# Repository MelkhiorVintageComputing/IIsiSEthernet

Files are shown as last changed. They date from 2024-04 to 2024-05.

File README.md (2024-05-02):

# SEthernet for the Macintosh IIsi

This is a design for a PDS Ethernet device for the Macintosh IIsi & other macintoshes with a similar PDS slot. This is not my own design, but a redesign in a different form factor of [the SEthernet/30 for the Macintosh SE/30](https://github.com/rhalkyard/SEthernet). It's meant to be gateware- (for the CPLD), firmware- (the declaration ROM) and software-compatible (the Ethernet driver) with the original.

Known issues:
* The silkscreen for the slotid is backward between '0' and '1' (the slotid are negative logic)
* The Flash ROM is wired bit-reversed. While it has no impact on data or any regular software, it does cause an issue with the 'command bytes' from the ROM programmer - the 'command bytes' need to be bit-reversed to work, so this design is not compatible with the standard programRom.

License is the same as the original:

The hardware components of this project (board designs and programmable logic) are licensed under the Strongly-Reciprocal CERN Open Hardware License, version 2.

Please see also [the comments on licensing of the original design](https://github.com/rhalkyard/SEthernet?tab=readme-ov-file#license).

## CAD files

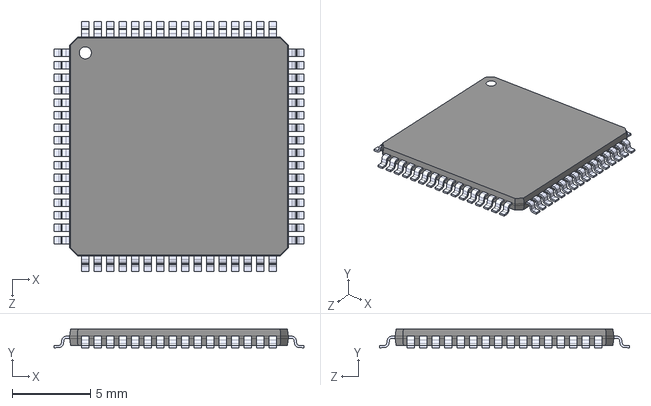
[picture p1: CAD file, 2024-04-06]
ENC624J600-I_PT.step
16.0 x 1.20 x 16.0 mm

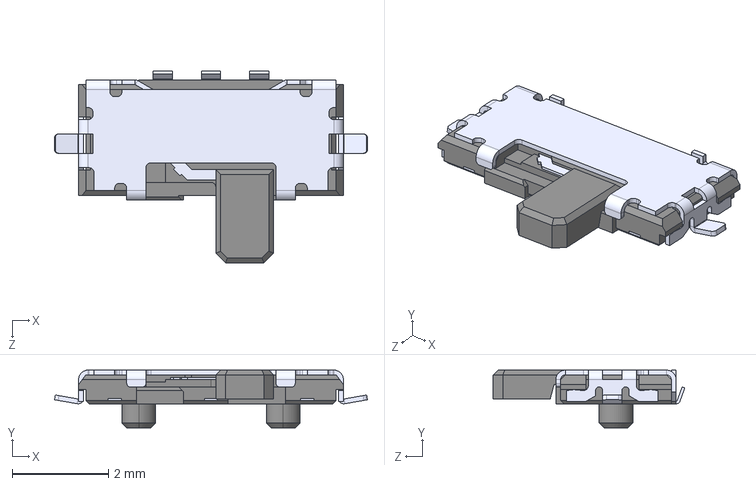
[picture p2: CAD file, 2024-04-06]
SSAJ110100.step
6.50 x 1.20 x 3.98 mm

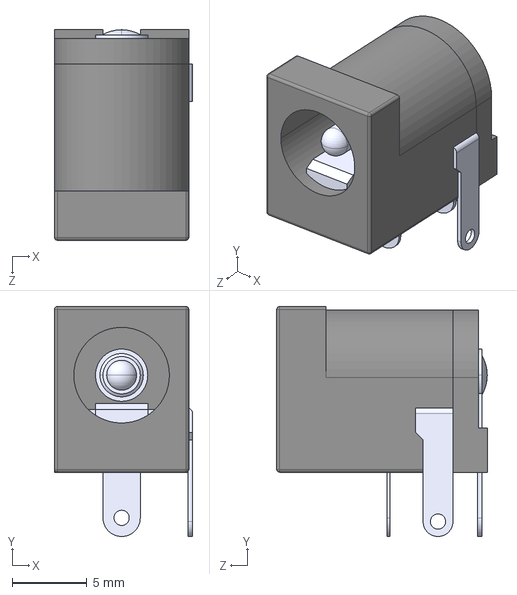
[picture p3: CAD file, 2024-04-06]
CON-SOCJ-2155--3DModel-STEP-56544.STEP
9.25 x 15.4 x 14.1 mm

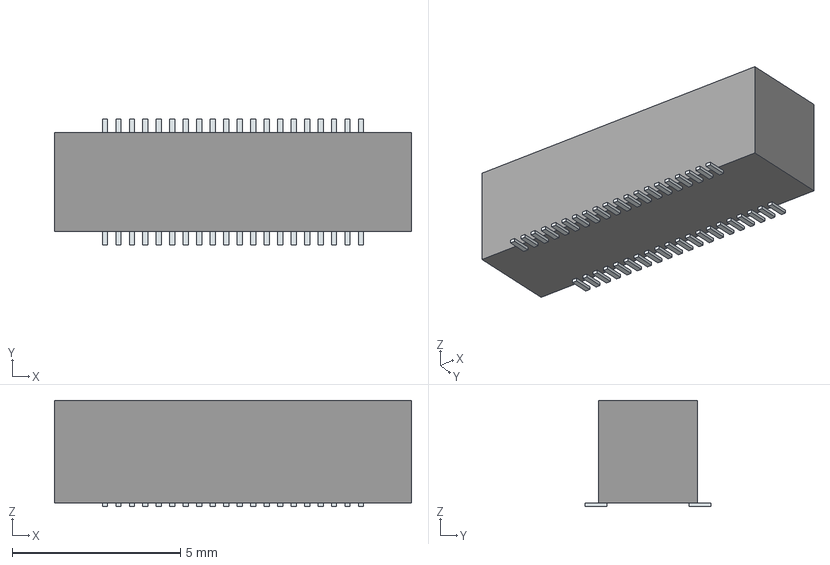
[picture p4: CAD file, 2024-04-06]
DF40HC_3.0_-40DS-0.4V_51_.stp
10.6 x 3.74 x 3.15 mm
Pins

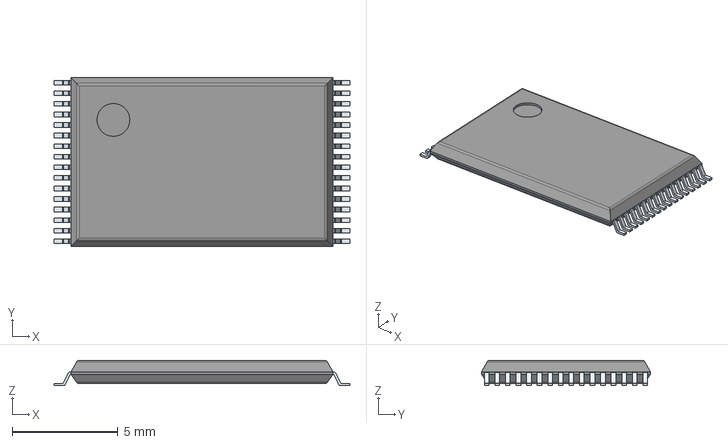
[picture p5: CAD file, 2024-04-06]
SST39SF010A-70-4C-WHE.stp
14.0 x 8.00 x 1.20 mm
PinsArrayLR

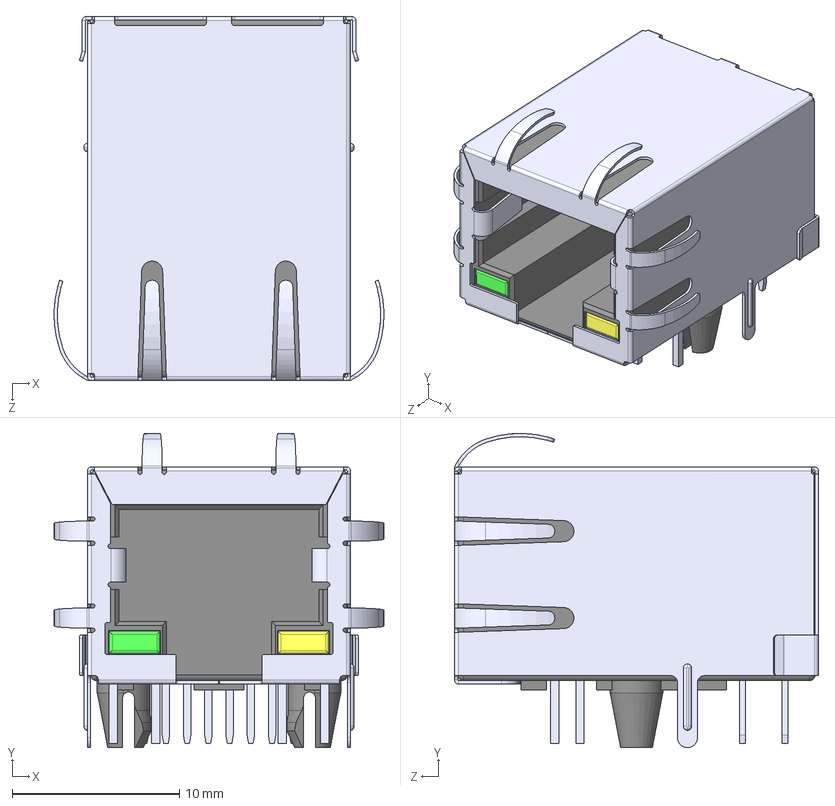
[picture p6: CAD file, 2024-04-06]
RJMG1BD3B8K1ANR--3DModel-STEP-56544.STEP
19.7 x 18.8 x 21.8 mm

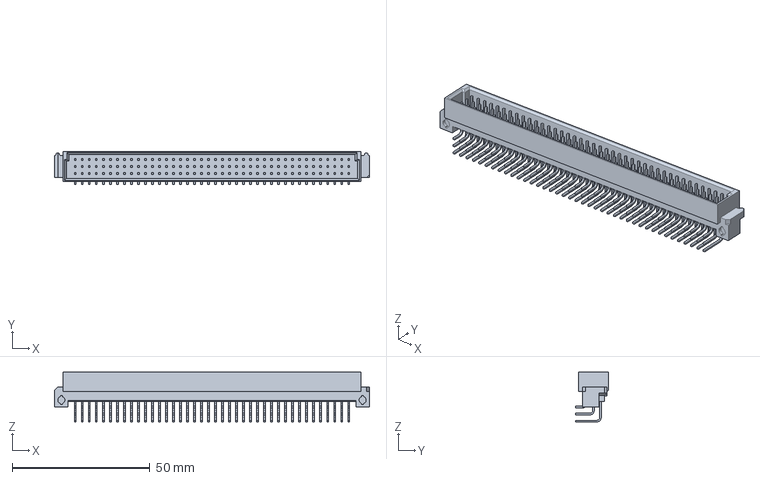
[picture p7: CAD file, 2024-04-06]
650906-5.stp
114.2 x 12.1 x 18.0 mm

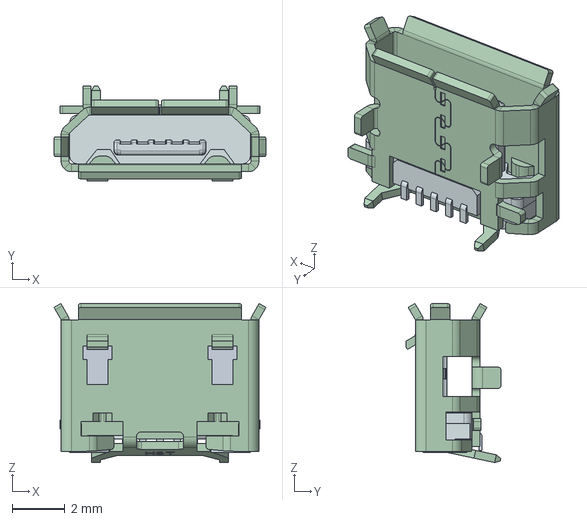
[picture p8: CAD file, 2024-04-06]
10103594-0001LF--3DModel-STEP-533217.STEP
8.04 x 3.60 x 6.03 mm

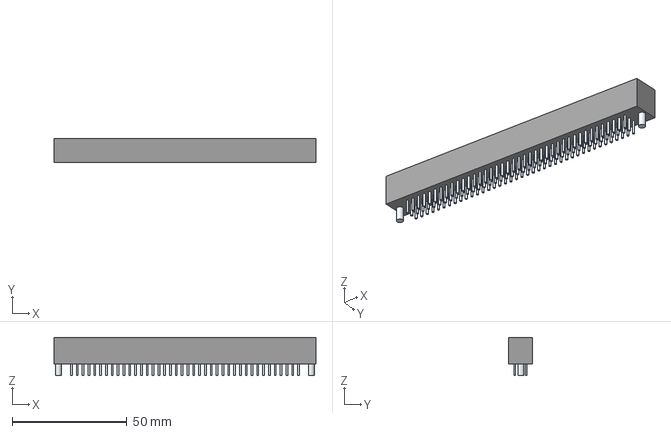
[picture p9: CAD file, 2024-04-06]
5535098-5.stp
114.3 x 10.6 x 16.6 mm
Leads

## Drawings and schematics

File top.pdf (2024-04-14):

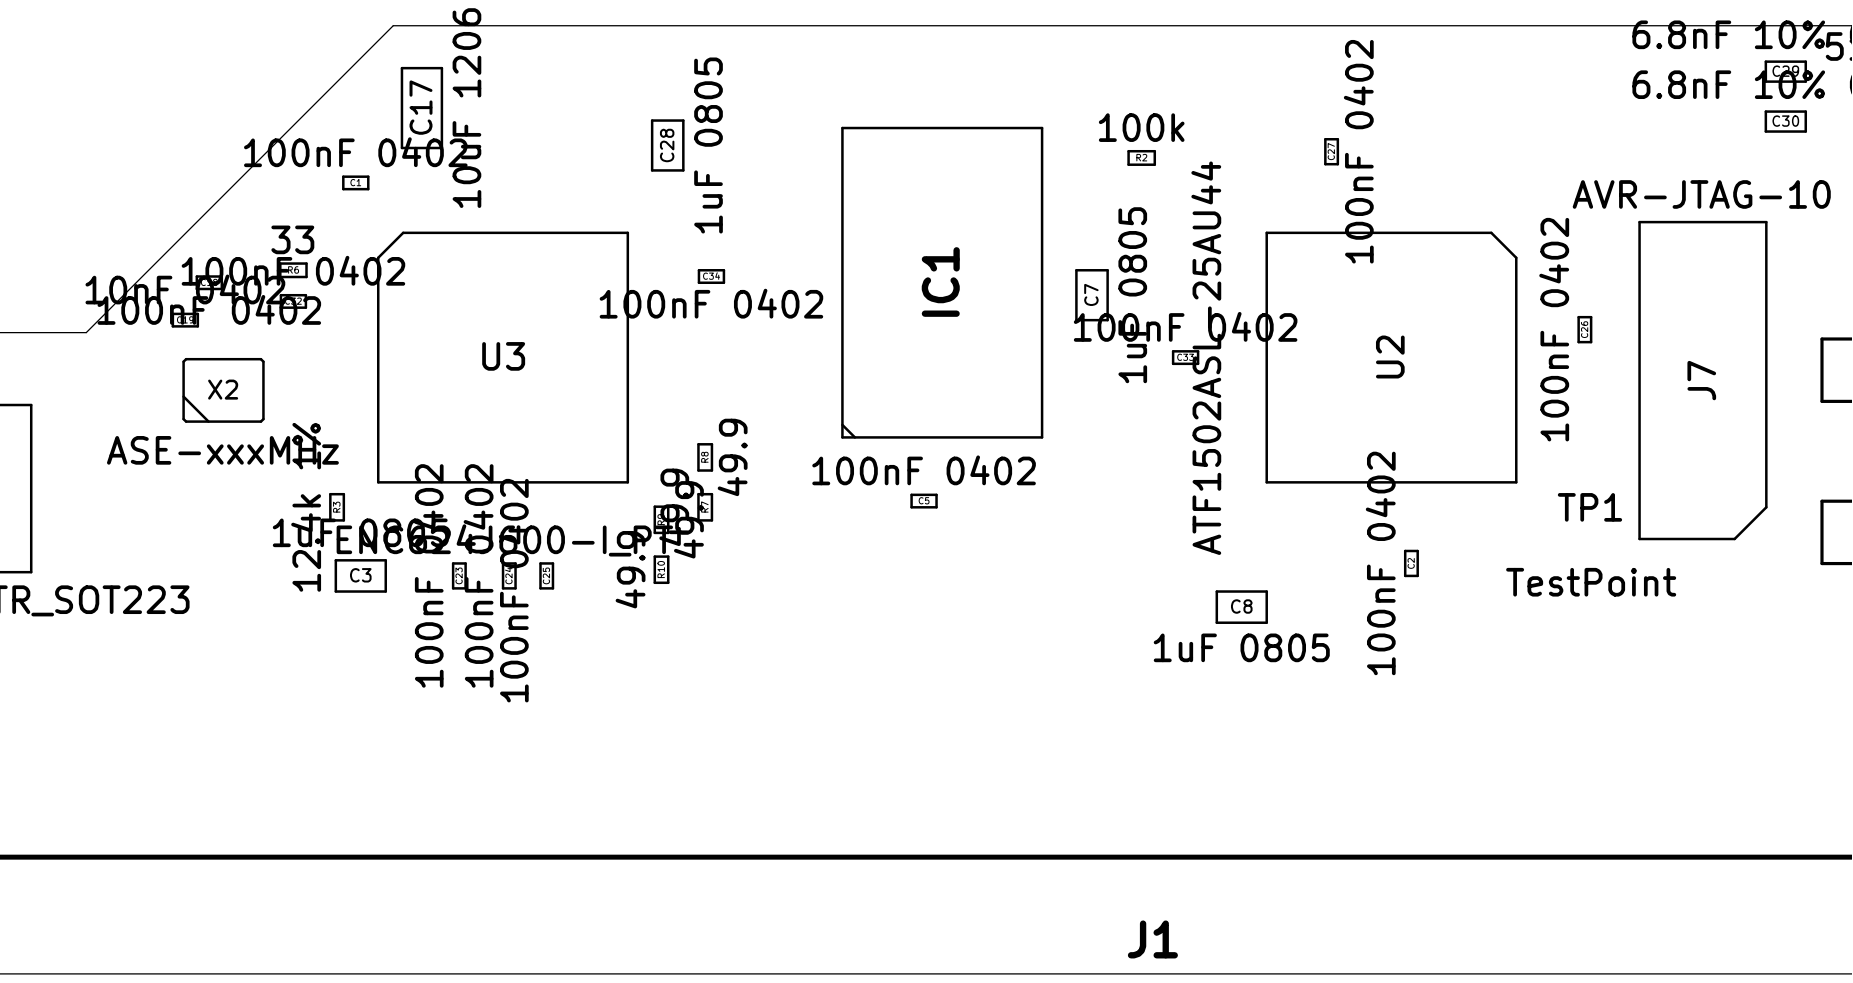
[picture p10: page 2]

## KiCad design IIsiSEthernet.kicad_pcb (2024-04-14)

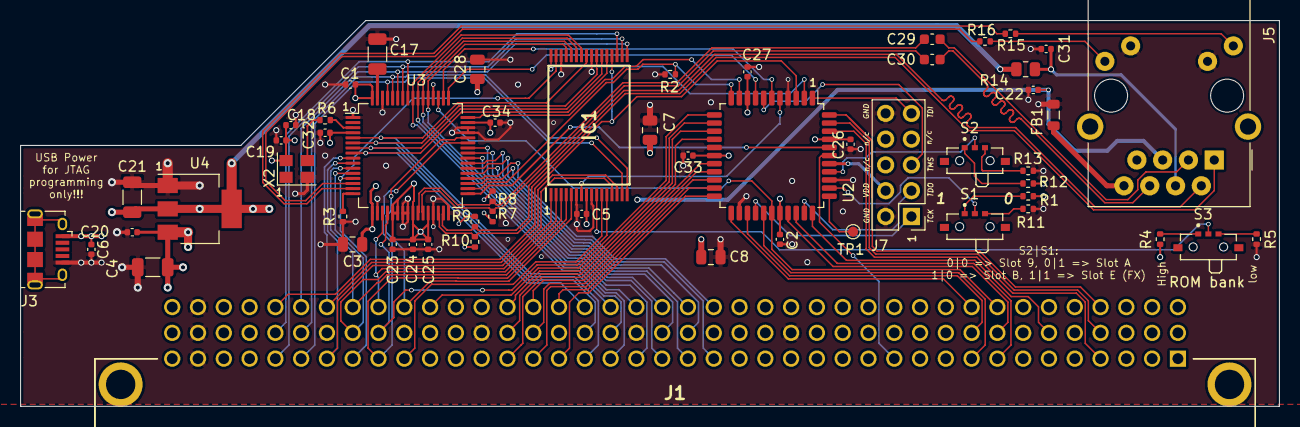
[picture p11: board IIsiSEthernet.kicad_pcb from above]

Board: 4 copper layers, 124.0 x 38.0 mm, 56 parts (0 on the bottom side), 94 nets.

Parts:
C1, C2, C5, C6, C18, C20, C23, C24, C25, C26, C27, C32, C33, C34: 100nF 0402; C_0402_1005Metric
C3, C7, C8, C28: 1uF 0805; C_0805_2012Metric
C4, C17, C21: 10uF 1206; C_1206_3216Metric
C19, C22, C31: 10nF 0402; C_0402_1005Metric
C29, C30: 6.8nF 10% 0603; C_0603_1608Metric
FB1: Ferrite_Bead; L_0805_2012Metric
IC1: SST39SF010A-70-4C-WHE; SOP50P1400X120-32N
J1: 650906-5; 6509065
J3: USB_B_Micro; USB_Micro-B_Amphenol_10118194_Horizontal
J5: RJ45_Amphenol_RJMG1BD3B8K1ANR
J7: AVR-JTAG-10; PinHeader_2x05_P2.54mm_Vertical
R1, R4, R5, R11, R12, R13: 10k; R_0402_1005Metric
R2: 100k; R_0402_1005Metric
R3: 12.4k 1%; R_0402_1005Metric
R6: 33; R_0402_1005Metric
R7, R8, R9, R10: 49.9; R_0402_1005Metric
R14: 10 1/12W 1%; R_0805_2012Metric
R15, R16: 510 0402; R_0402_1005Metric
S1, S2, S3: SSAJ110100; SW_SSAJ110100
TP1: TestPoint; TestPoint_Pad_D1.0mm
U2: ATF1502ASL-25AU44; LQFP-44_10x10mm_P0.8mm
U3: ENC624J600-I_PT; TQFP-64_10x10mm_P0.5mm
U4: LD1117S33TR_SOT223; SOT-223-3_TabPin2
X2: ASE-xxxMHz; Oscillator_SMD_Abracon_ASE-4Pin_3.2x2.5mm

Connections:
+3V3: C1.1, C3.1, C18.1, C19.1, C21.1, C23.1, C24.1, C25.1, C28.1, C32.1, C34.1, R9.2, R10.2, R14.1, U3.4, U3.17, U3.21, U3.22, U3.25, U3.28, U3.47, U3.52, U3.64, U4.2, X2.4
+5V: C2.1, C4.1, C5.1, C6.1, C7.1, C8.1, C20.1, C26.1, C27.1, C33.1, IC1.8, J1.A37, J1.B13, J1.B19, J1.B25, J1.B31, J1.B37, J1.C37, J3.1, R1.2, R4.2, R12.2, U2.9, U2.17, U2.29, U2.41, U4.3
/Ethernet/RBIAS: R3.1, U3.16
/Ethernet/TP34: TP1.1, U2.34
/Ethernet/VCAP: C17.1, U3.63
/eth_conn/ETH_3V3: C31.1, J5.R4, R14.2
/eth_conn/RCT: C22.2, J5.R5, R7.2, R8.2
/eth_conn/RD+: C29.1, J5.R3
/eth_conn/RD-: C30.1, J5.R6
A0: IC1.20, J1.C36, U2.3
A1: IC1.19, J1.B36, U3.57
A2: IC1.18, J1.A36, U3.58
A3: IC1.17, J1.C35, U3.59
A4: IC1.16, J1.B35, U3.60
A5: IC1.15, J1.A35, U3.61
A6: IC1.14, J1.C34, U3.9
A7: IC1.13, J1.A34, U3.10
A8: IC1.3, J1.C33, U3.11
A9: IC1.2, J1.B33, U3.12
A10: IC1.31, J1.A33, U3.13
A11: IC1.1, J1.C32, U3.19
A12: IC1.12, J1.B32, U3.20
A13: IC1.4, J1.A32, U3.43
A14: IC1.5, J1.C31, U3.44
A15: IC1.11, J1.A31
A16: J1.C30, U2.12
A24: J1.C27, U2.13
A25: J1.B27, U2.14
A26: J1.A27, U2.15
A27: J1.C26, U2.18
A28: J1.B26, U2.19
A29: J1.A26, U2.20
A30: J1.C25, U2.21
A31: J1.A25, U2.22
CLK_25_000: R6.1, U3.3
D16: J1.A19, U3.35
D17: J1.C19, U3.36
D18: J1.A20, U3.37
D19: J1.B20, U3.38
D20: J1.C20, U3.39
D21: J1.A21, U3.40
D22: J1.B21, U3.41
D23: J1.C21, U3.42
D24: IC1.29, J1.A22, U3.53
D25: IC1.28, J1.C22, U3.54
D26: IC1.27, J1.A23, U3.55
D27: IC1.26, J1.B23, U3.56
D28: IC1.25, J1.C23, U3.5
D29: IC1.23, J1.A24, U3.6
D30: IC1.22, J1.B24, U3.7
D31: IC1.21, J1.C24, U3.8
ETH_B0SEL: U2.6, U3.50
ETH_B1SEL: U2.10, U3.48
ETH_CLKOUT: U2.40, U3.33
ETH_CS: U2.8, U3.49
ETH_~INT: R2.1, U2.11, U3.34
Earth: FB1.1, J5.R8
GND: C1.2, C2.2, C3.2, C4.2, C5.2, C6.2, C7.2, C8.2, C17.2, C18.2, C19.2, C20.2, C21.2, C22.1, C23.2, C24.2, C25.2, C26.2, C27.2, C28.2, C31.2, C32.2, C33.2, C34.2, FB1.2, IC1.6, IC1.9, IC1.24, IC1.30, J1.A39, J1.B16, J1.B22, J1.B28, J1.B34, J1.B39, J1.C39, J3.5, J5.L2, J5.L3, J7.2, J7.10, R2.2, R3.2, R5.2, R11.2, R13.2, U2.4, U2.16, U2.24, U2.36, U3.1, U3.18, U3.23, U3.24, U3.29, U3.32, U3.45, U3.46, U3.62, U4.1, X2.2
JTAG_TCK: J7.1, U2.26
JTAG_TDI: J7.9, U2.1
JTAG_TDO: J7.3, U2.32
JTAG_TMS: J7.5, U2.7
JTAG_VDD: J7.4, U2.38
LEDA: R15.2, U3.15
LEDB: R16.2, U3.14
unnamed: J5.L1, R16.1
unnamed: J5.L4, R15.1
unnamed: R1.1, S1.1
unnamed: R4.1, S3.1
unnamed: R5.1, S3.2
unnamed: R6.2, X2.3
unnamed: R11.1, S1.2
unnamed: R12.1, S2.1
unnamed: R13.1, S2.2
ROM_BANK: IC1.10, S3.C
SIZ0: J1.B9, U2.25
SIZ1: J1.A9, U2.27
TPIN+: C29.2, R8.1, U3.26
TPIN-: C30.2, R7.1, U3.27
TPOUT+: J5.R1, R10.1, U3.30
TPOUT-: J5.R2, R9.1, U3.31
~AS: J1.C9, U2.23
~DS: J1.B6, U2.33
~DSACK0: J1.B8, U2.30
~DSACK1: J1.A8, U2.31
~IRQ1: J1.C4, U2.44
~IRQ2: J1.B4, U2.43
~IRQ3: J1.A4, U2.42
~RESET: J1.A12, U2.39
~ROM_OE: IC1.32, U2.2
~ROM_WE: IC1.7, U2.5
~RW: J1.C8, U2.28, U3.51
~SLOTID_0: S1.C, U2.35
~SLOTID_1: S2.C, U2.37

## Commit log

2024-04-06 initial import
    [10103594-0001LF--3DModel-STEP-533217.STEP, 5535098-5.stp, 650906-5.stp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]
2024-04-07 minor stuff
    [IIsiSEthernet.kicad_pcb]
2024-04-13 cleanups, switch for ROM bank
    [IIsiSEthernet-B_Cu.gbr, IIsiSEthernet-B_Mask.gbr, IIsiSEthernet-B_Paste.gbr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]
2024-04-14 silk cleanup
    [IIsiSEthernet-B_Cu.gbr, IIsiSEthernet-B_Mask.gbr, IIsiSEthernet-B_Paste.gbr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]
2024-04-14 27->33 ohms (basic...)
    [IIsiSEthernet-B_Cu.gbr, IIsiSEthernet-B_Mask.gbr, IIsiSEthernet-B_Paste.gbr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]
